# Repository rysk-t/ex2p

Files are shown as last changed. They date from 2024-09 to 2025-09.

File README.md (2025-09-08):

# Ex2p / Ex2pO
Extra lens mount for 2-photon microscope
 - extend imaging capability
 - excitation of neurons by optogenetic stimulation with narrow-band laser

|Imaging flexibility|Optogenetical stimulation (under-filled setting)|
|---|---|
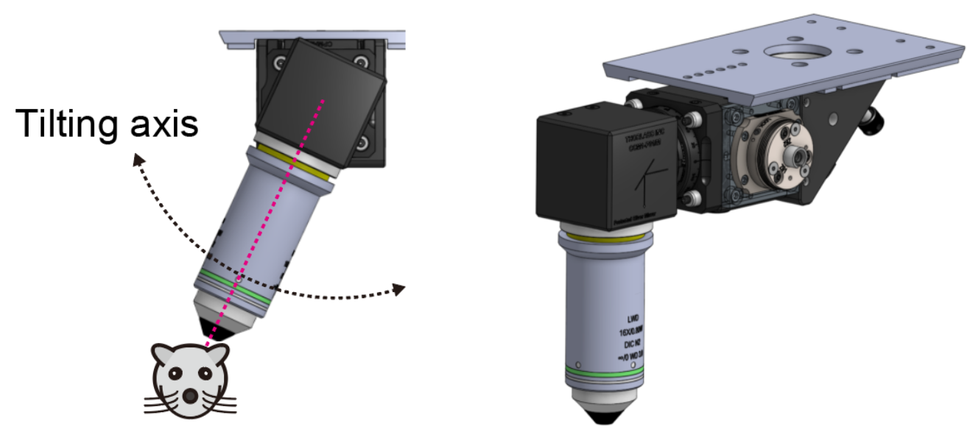
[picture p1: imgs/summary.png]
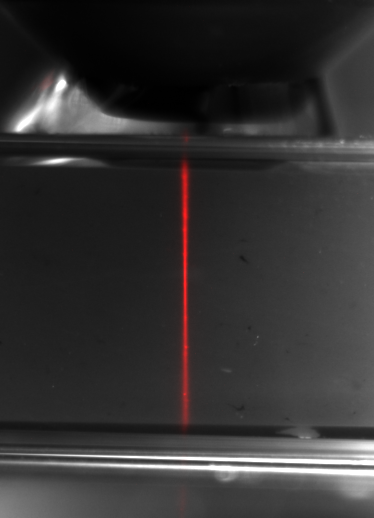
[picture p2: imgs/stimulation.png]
| | |

# Hardwares
 - Construction parts are listed in this [link](https://docs.google.com/spreadsheets/d/1m83LMHQkvfFSLj0JxW27Dom7R-7Ju0coneMxOGsIGas/edit?usp=sharing)
 - Analog discovery 2 (Digilent) is used to generate TTL signal for stimulation.

## Construction

## Ex2p
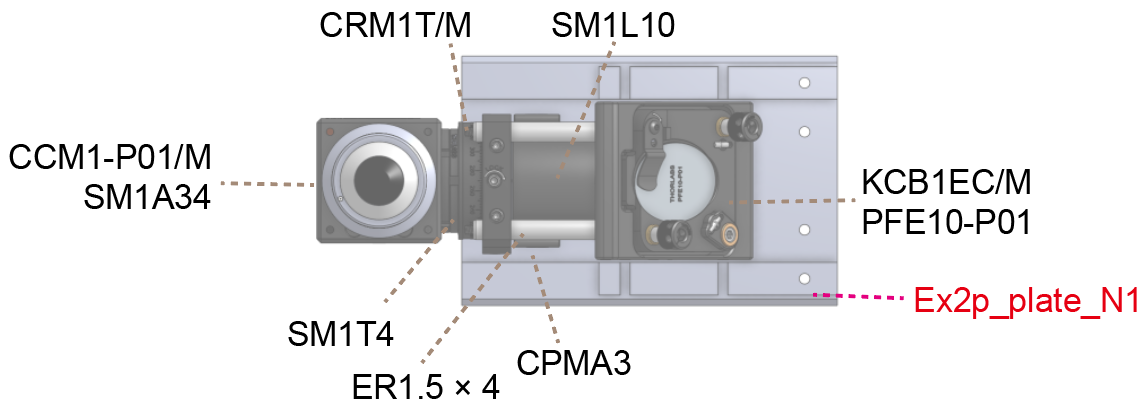
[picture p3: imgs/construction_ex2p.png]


## Ex2pO
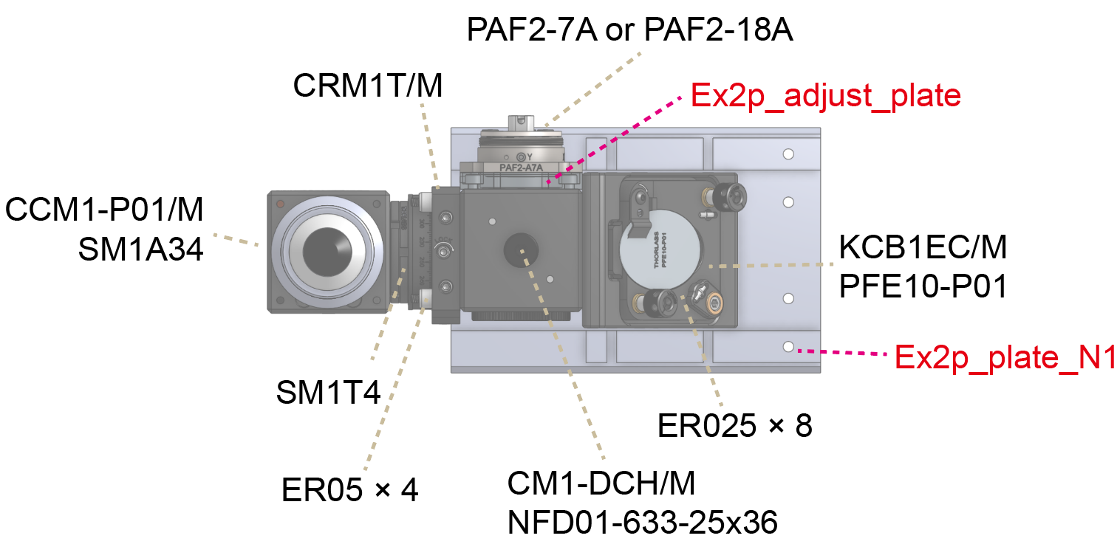
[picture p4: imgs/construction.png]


 - Red-colored parts are the original parts of the Ex2p Nikon version.
 - Most of the parts were commercial parts from Thorlab.
 - FC/APC laser input ports were attached to the dichroic mount.
   - Various narrow-band and fast switchable LD laser sources are recommended (e.g., Omicron Luxx+, Coherent OBIS LX).
  
[3d-data files (.stl)  are available](https://github.com/rysk-t/ex2p/tree/main/Ex2pO_parts).

## Circuits configuration
Using Analog Discovery 2 with a custom-made breakout board, TTL for laser modulation was quickly configurable.
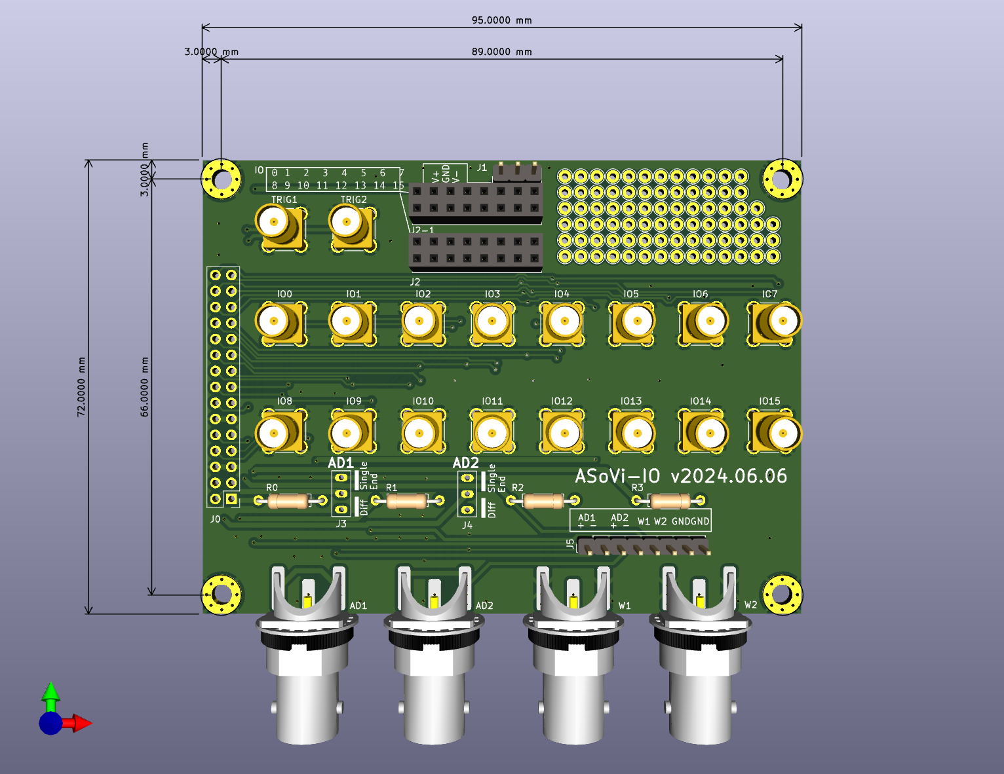
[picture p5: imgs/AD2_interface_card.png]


[PCB files (.grb)  are available](https://github.com/rysk-t/ex2p/tree/main/Ex2pO_parts/breakoutboard).

breakout board designed by Kota OKADA and Ryosuke TAKEUCHI (Nagoya University)

# Citation
Takeuchi, R. F., Ishida, R., Kamaguchi, R., Nishimura, M., Tsutsumi, K., Ito, K. N., Adachi, S., Isobe, K., & Osakada, F. (2025). An extension module for a two-photon microscope enables flexible in vivo imaging and all-optical physiology. iScience, 113525.

[https://doi.org/10.1016/j.isci.2025.113525](https://doi.org/10.1016/j.isci.2025.113525)

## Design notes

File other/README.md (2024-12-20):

# Other parts for using Ex2p
## Head-fixation of mice

 - **B1v2b.stl**: head-frame implant for mice (for two-photon imaging, Ephys, and transcranial wide-field imaging)
 - **fix_headframe.stl**: fixation metal parts L/R
 - **Head_Cover_Short2p.stl**: 3d-print parts for preventing direct stimulation of retina through eyes

|Isometric view of construction||
|---|---|
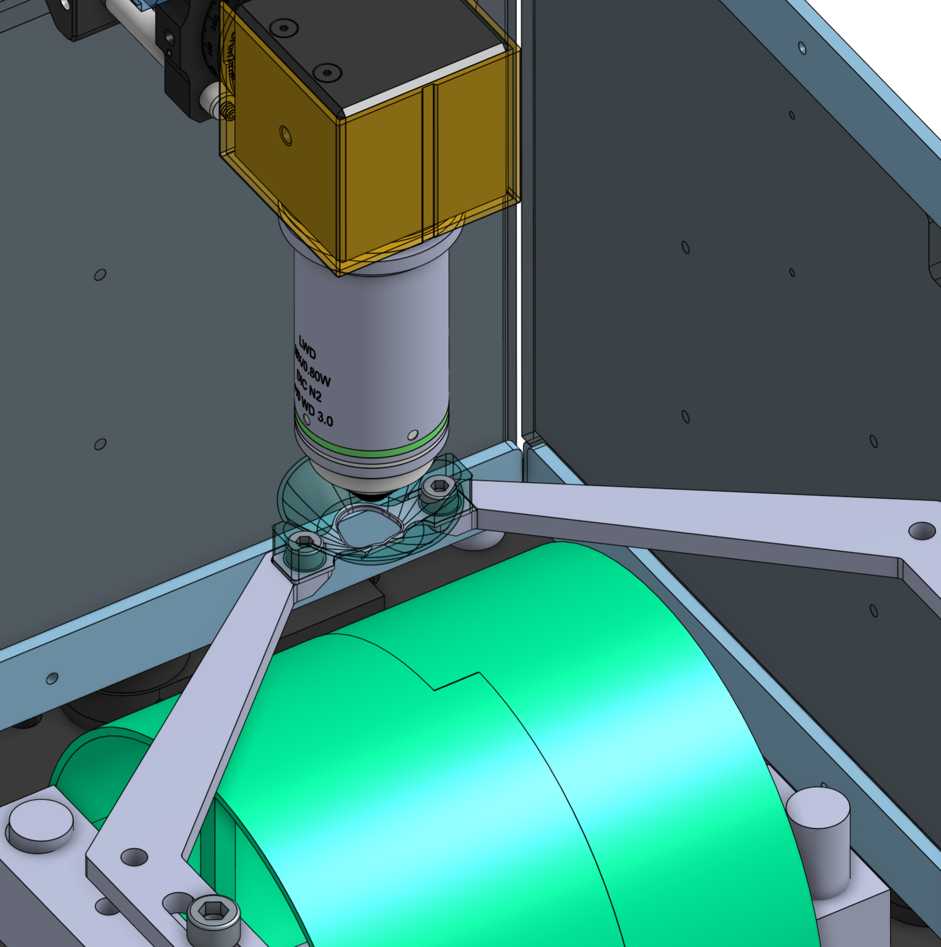
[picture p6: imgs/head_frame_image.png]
| ||

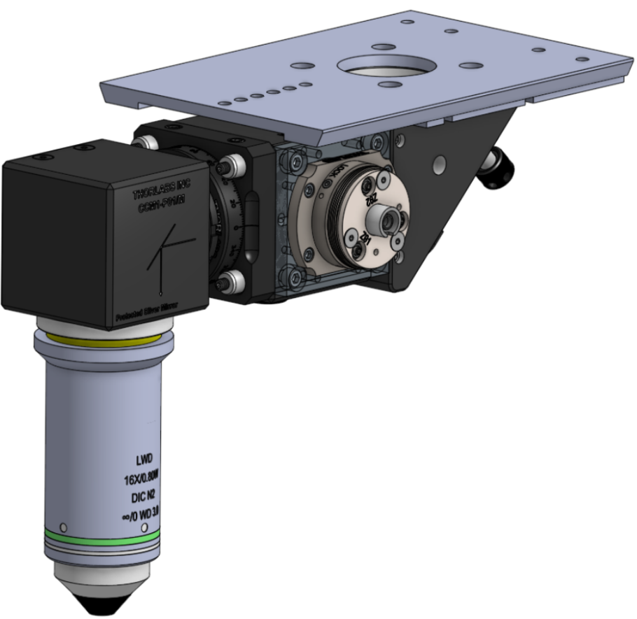
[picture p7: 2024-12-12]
imgs/isom.img.png

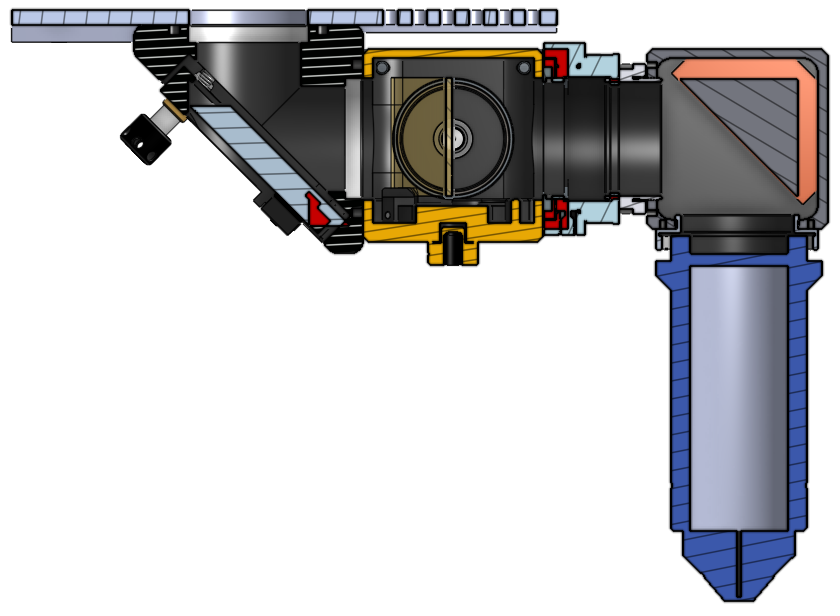
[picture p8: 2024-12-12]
imgs/orth.png

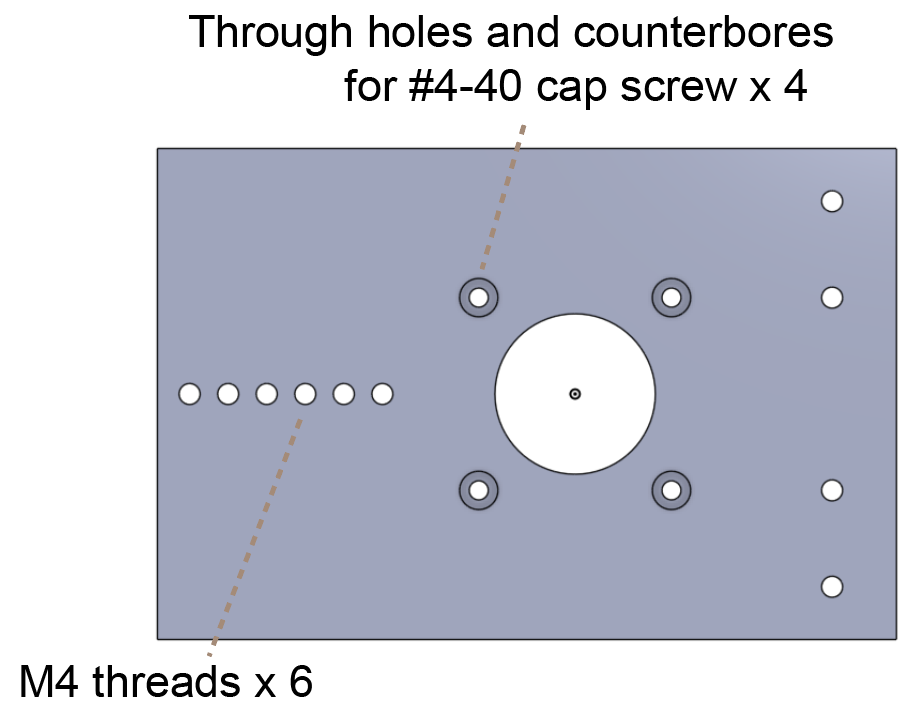
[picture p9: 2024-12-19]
imgs/hole_infos.png

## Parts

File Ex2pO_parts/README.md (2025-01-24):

# Quick guide for Ex2pO
 - Ex2pO utilizes Thorlabs 30 mm cage system for main construction.
 - FC/APC laser input ports were attached to the dichroic mount.
   - Various narrow-band and fast switchable LD laser sources are recommended (e.g. Omicron Luxx+, Coherent OBIS LX).
   - for precise alignment, Thorlabs SM05 kinematic mount is recommended.
   - any notch-dichroic filter (25x36 size) can be used. Please select the optimal wavelength for your application.

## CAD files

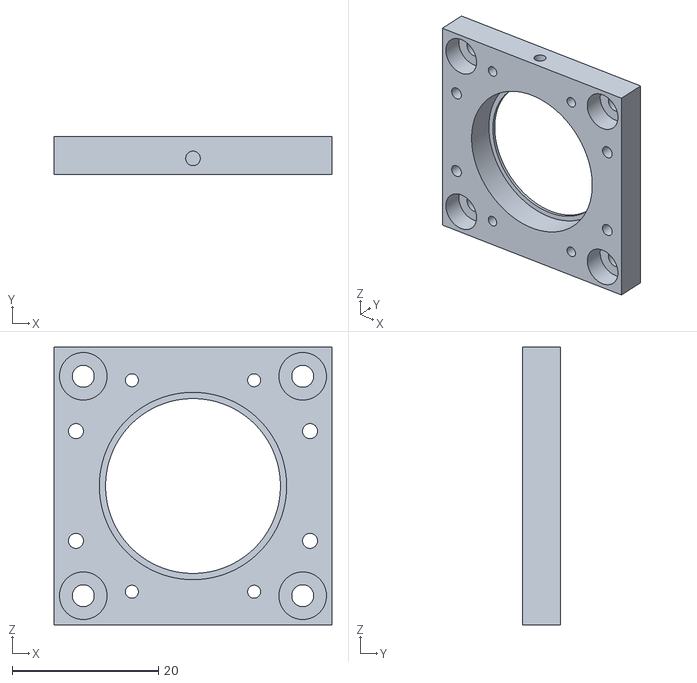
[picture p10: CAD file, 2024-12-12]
Ex2pO_parts/adjust_plate_01_v2.stl
38.0 x 5.20 x 38.0

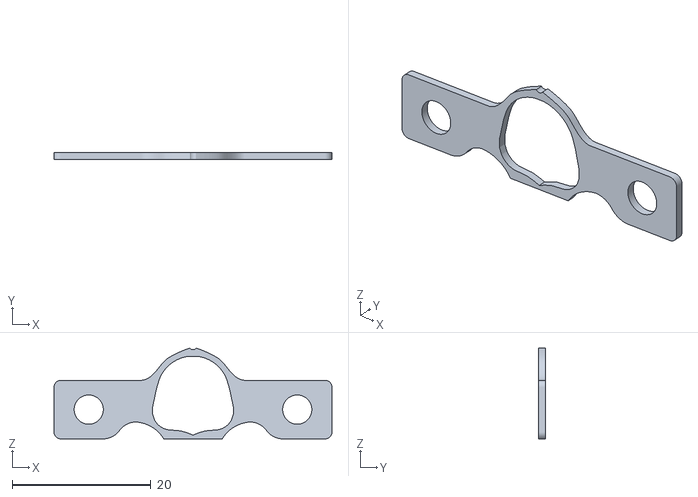
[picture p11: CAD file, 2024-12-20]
other/B1v2b.stl
40.0 x 1.00 x 13.1

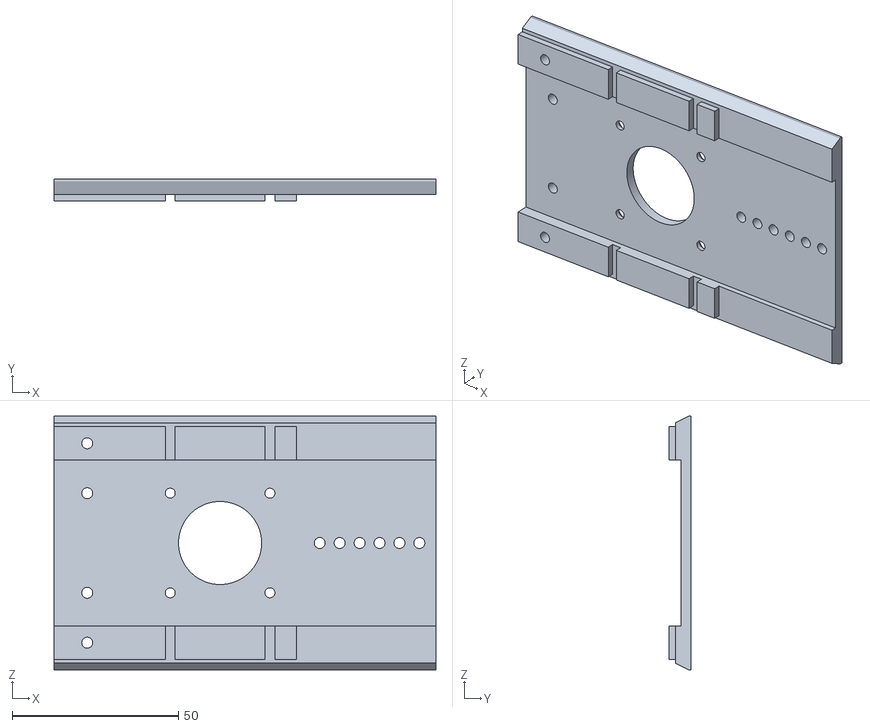
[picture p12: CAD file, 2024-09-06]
Ex2pO_parts/Ex2p_plate_N1.stl
115.0 x 6.70 x 76.4

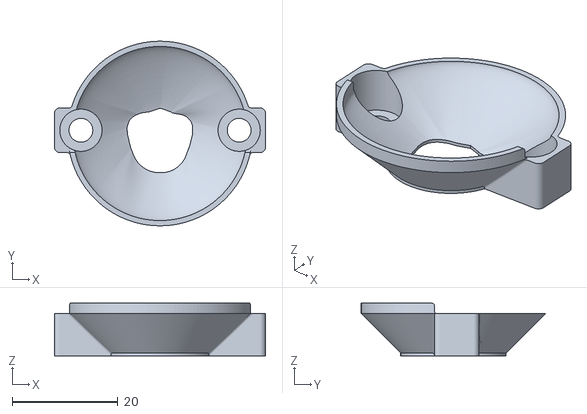
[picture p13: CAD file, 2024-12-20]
other/Head_Cover_Short2p.stl
40.0 x 35.0 x 10.0

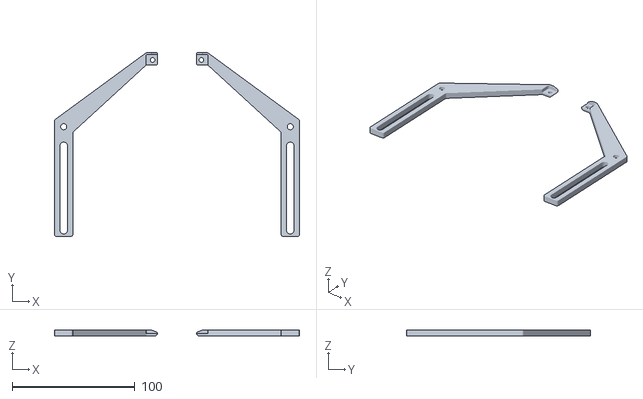
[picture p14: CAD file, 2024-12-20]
other/fix_headframe.stl
200.0 x 150.0 x 5.00

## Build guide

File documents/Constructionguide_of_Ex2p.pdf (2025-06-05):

# Assembly guide of Ex2p

## Step 1

1. Secure the four ER025 rods on plate_N1 with #4-40 low head screw.
2. Secure the CPMA3 into plate_N1 with an M4 6 mm screw.

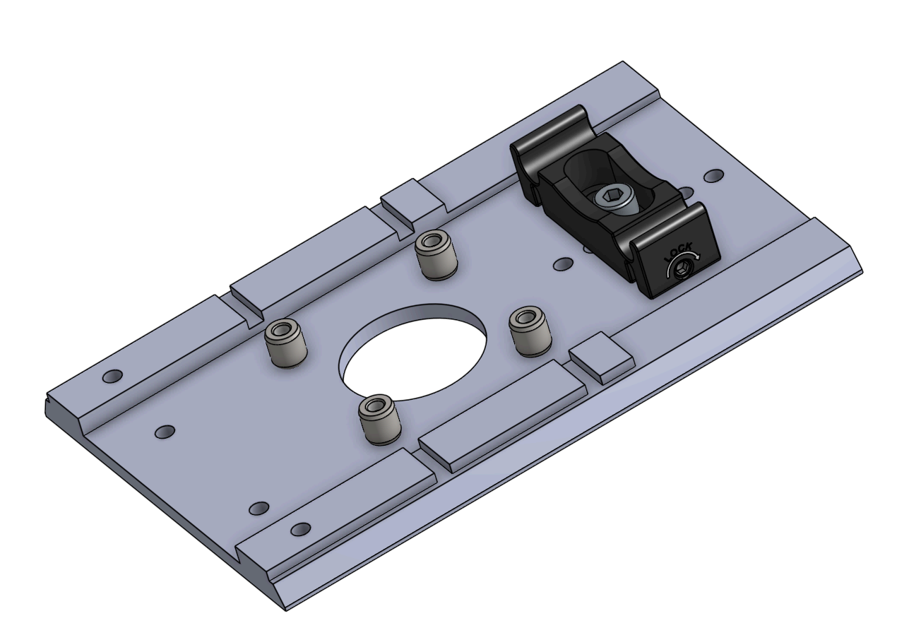
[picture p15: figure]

3. Install the Elliptical Mirror (PFE10-P01) into the KCB1EC/M.
4. Connect the four ER1.5 rods into the KCB1EC/M (Remove the set screws before connect).
5. Connect the plate_N1 and KCB1EC/M. Secure the KCB1EC/M with side screw.
6. Secure the ER1.5 with the set screw of CPMA3.

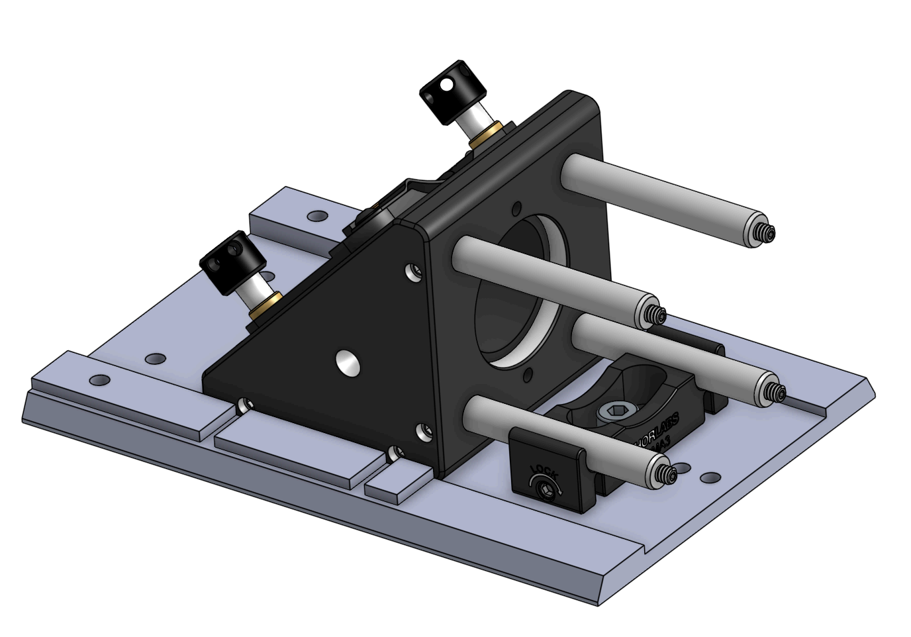
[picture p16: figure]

7. Connect the SM1L10 and KCB1EC/M.
8. Connect the CRM1T/M and CCM1-P01/M with SM1T4.

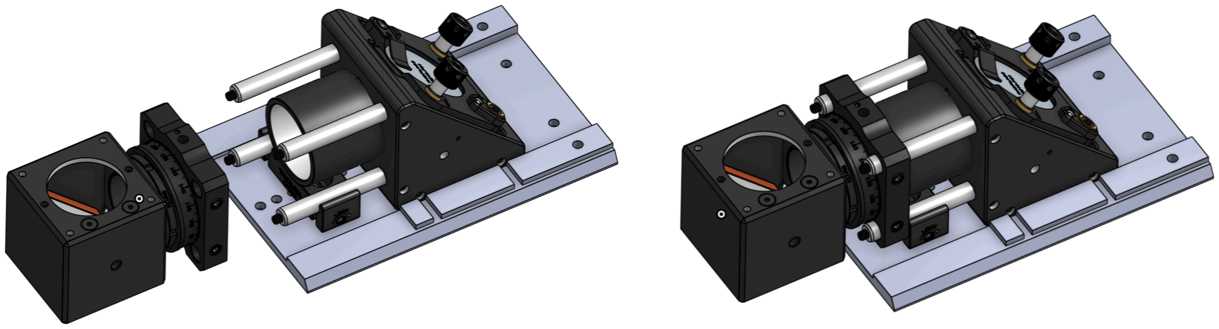
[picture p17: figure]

## Step 2

9. Secure the main unit to the microscope.
10. Secure the laser beam profiler or IR viewer target to the CM1-DCH/M (a beam profiler is recommended).
11. Center the scan mirrors of the two-photon microscope.
12. Open the shutter and emit the IR laser. Adjust the mirror on the KCB1EC/M so that the laser is centered on the laser beam profiler. Continue adjusting until the laser remains centered even when the distance along the optical axis to the laser beam profiler changes.
13. Close the shutter to stop the IR laser.
14. Adjust the angle of the objective lens.

## Notes:

- Be careful not to touch the adjustment screws on the KCB1EC/M after alignment.
- Briefly check the alignment before an experiment.
- When tilting the objective lens, loosen the lock screw(s) on the CRM1T/M, adjust the angle as needed, and then secure it.

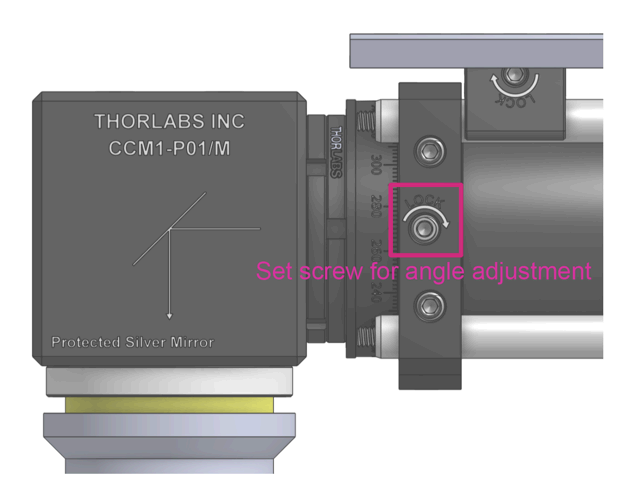
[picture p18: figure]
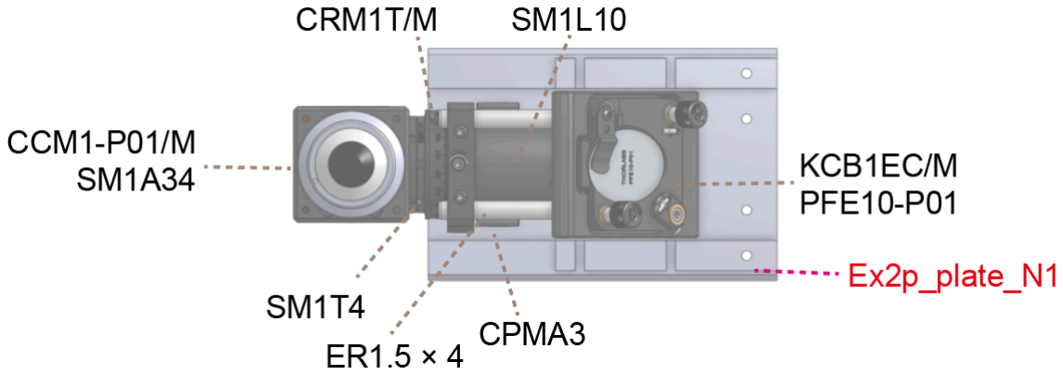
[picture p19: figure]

## Parts list

Company | Product ID | # | Detail
Thorlabs | SM1A34 | 1 | SM1A34 - Adapter with External SM1 Threads and Internal M32 x 0.75 Threads
| KCB1EC/M | 1 | KCB1EC/M - Right-Angle Kinematic Elliptical Mirror Mount with Smooth Cage Rod Bores, 30 mm Cage System and SM1 Compatible, M4 and M6 Mounting Holes
| PFE10-P01 | 1 PFE10-P01 - 1" Protected Silver Elliptical Mirror, 450 nm - 20 µm
| CCM1-P01/M | 1 | CCM1-P01/M - 30 mm Cage Cube-Mounted Protected Silver Turning Mirror, M4 Tap
| SM1L10 | 1 | SM1L10 - SM1 Lens Tube, 1.00" Thread Depth, One Retaining Ring Included
| ER025 | 4 | ER025 - Cage Assembly Rod, 1/4" Long, Ø6 mm
| ER1.5-P4 | 1 ER1.5-P4 - Cage Assembly Rod, 1.5" Long, Ø6 mm, 4 Pack
| CRM1T/M | 1 | CRM1T/M - Cage Rotation Mount for Ø1" Optics, SM1 Threaded, M4 Tap
| SM1T4 | 1 | SM1T4 - SM1 (1.035"-40) Coupler, External Threads, Fixed Shoulder and Locking Ring
| CPMA3 | 1 CPMA3 - Snap-On 30 mm Cage Mounting Bracket, #8 (M4) Slot
DIY parts | Ex2p_plate_N1 | 1
Other | #4-40 low head cap screws | 4
| SPW502 | 1 | SPW502 - Spanner Wrench for Slotted SM05, SM1, and C-Mount Locking Rings
Thorlabs | SM1A34 | 1 | SM1A34 - Adapter with External SM1 Threads and Internal M32 x 0.75 Threads
| KCB1EC/M | 1 | KCB1EC/M - Right-Angle Kinematic Elliptical Mirror Mount with Smooth Cage Rod Bores, 30 mm Cage System and SM1 Compatible, M4 and M6 Mounting Holes
| PFE10-P01 | 1 PFE10-P01 - 1" Protected Silver Elliptical Mirror, 450 nm - 20 µm
| CCM1-P01/M | 1 | CCM1-P01/M - 30 mm Cage Cube-Mounted Protected Silver Turning Mirror, M4 Tap
| SM1L10 | 1 | SM1L10 - SM1 Lens Tube, 1.00" Thread Depth, One Retaining Ring Included

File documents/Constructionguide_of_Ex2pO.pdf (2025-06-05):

## Assembly guide of Ex2pO

## Step 1

1. Install the Elliptical Mirror (PFE10-P01) into the KCB1EC/M.
2. Install the Dichroic Mirror (NFD01-633) into the CCM1-P01/M.
3. Screw the SM1CP2 onto the side of the CCM1-P01/M.
4. Screw the adjust_plate_v2 onto the face of the CCM1-P01/M, opposite the SM1CP2.
5. Screw the Fiber Port (e.g. PAF2-7A or PAF2A-18A) into the adjust_plate_v2.
6. Screw the four ER025 rods into the CCM1-P01/M. Remove the remaining set screws.
7. Connect the CCM1-P01/M and the KCB1EC/M. Tighten the side screws on the KCB1EC/M.

## Step 2

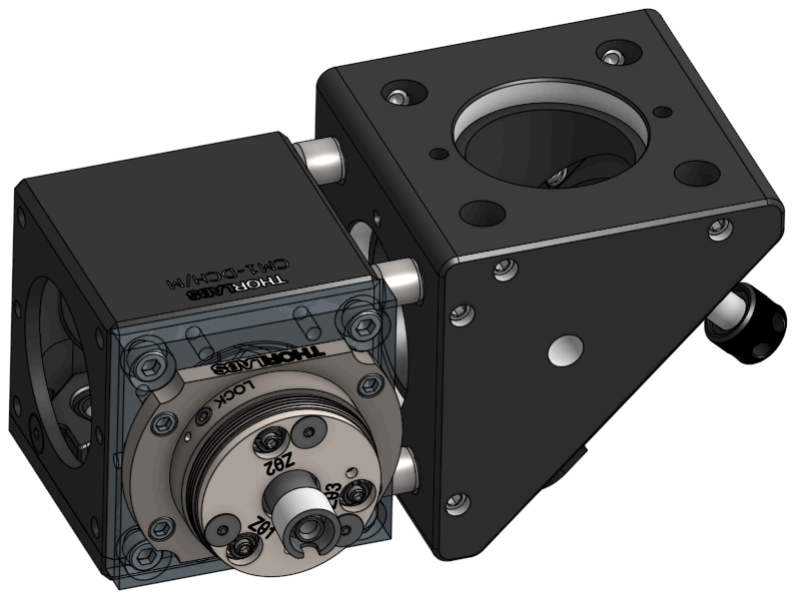
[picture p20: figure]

8. Screw the ER05 rods into the face opposite the ER025 rods.
9. Pass the CRM1T/M over the ER05 rods and secure it.
10. Secure the CRM1T/M and CM1-DCH/M together using the SM1T4 (tighten firmly with the SPW502 spanner wrench).

## Step 3

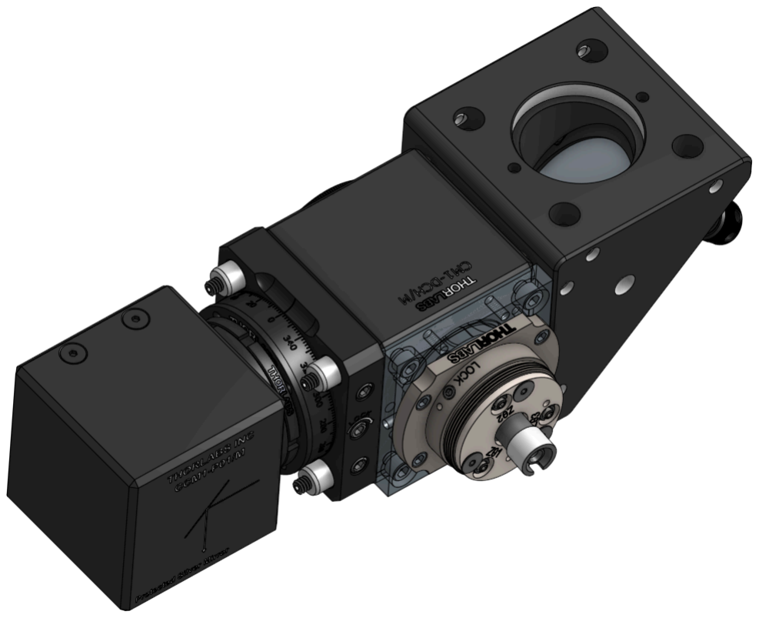
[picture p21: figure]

11. Remove all setscrews from the four ER025 rods.
12. Install this assembly on top of the KCB1EC/M. Tighten the side screws to secure it.
13. Secure plate_N1 from the top using #4-40 Low-head screws.
14. Install the blocking filter (e.g., FESH600 for 638 nm laser) in front of the detector.

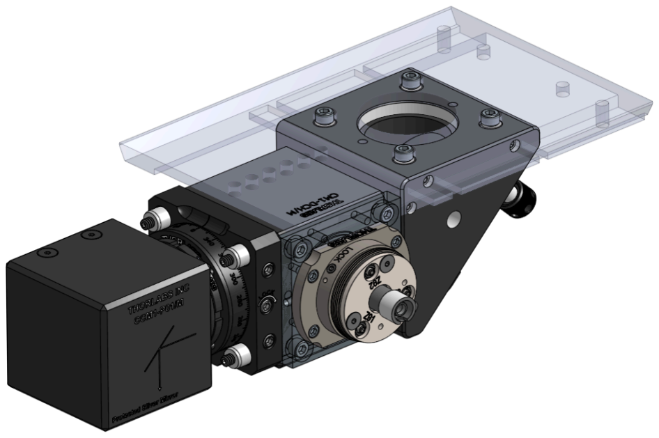
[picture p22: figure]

## Step 4

15. Secure the main unit to the microscope.
16. Secure the laser beam profiler or IR viewer target to the CM1-DCH/M (a laser beam profiler is recommended).
17. Center the scan mirrors of the two-photon microscope.
18. Open the shutter and emit the IR laser. Adjust the mirror on the KCB1EC/M so that the laser is centered on the laser beam profiler. Continue adjusting until the laser remains centered even when the distance along the optical axis to the laser beam profiler changes.
19. Close the shutter to stop the IR laser.
20. Insert the fiber for the 1P (one-photon) laser into the PAF2-7A/PAF2A-18A. Adjust the screws on the PAF2-7A/PAF2A-18A so that the 1P laser is centered on the laser beam profiler. Additionally, adjust the collimation if necessary.

## Notes:

- Be careful not to touch the adjustment screws on the KCB1EC/M.
- Briefly check the alignment before an experiment.
- When tilting the objective lens, loosen the lock screw(s) on the CRM1T/M, adjust the angle as needed, and then secure it.

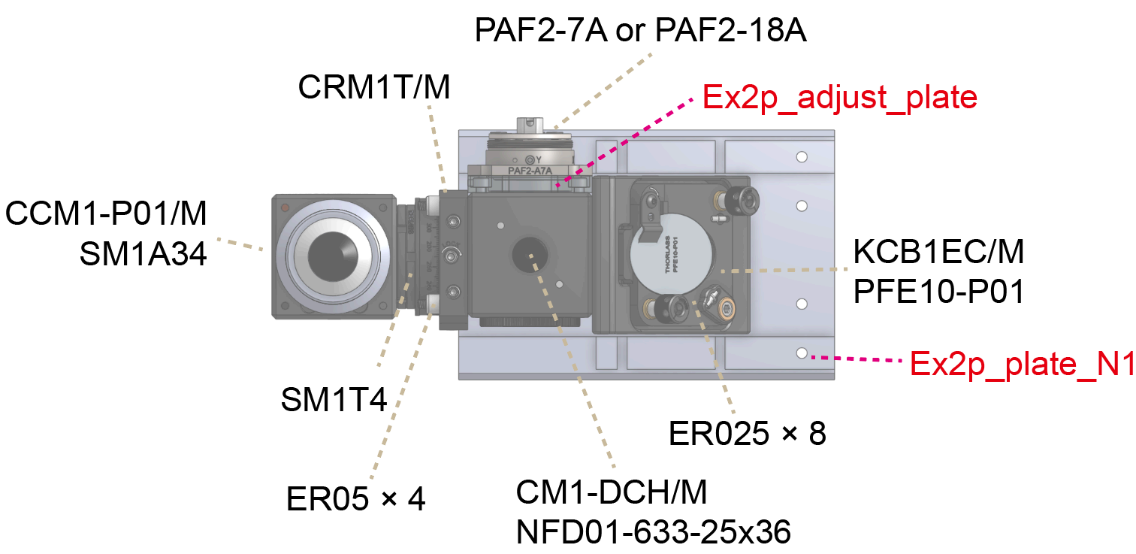
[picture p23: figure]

## Parts list

Company | Product ID | # | Detail
Thorlabs | SM1A34 | 1 | SM1A34 - Adapter with External SM1 Threads and Internal M32 x 0.75 Threads
| CCM1-P01/M | 1 | CCM1-P01/M - 30 mm Cage Cube-Mounted Protected Silver Turning Mirror, M4 Tap
| SM1T4 | 1 | SM1T4 - SM1 (1.035"-40) Coupler, External Threads, Fixed Shoulder and Locking Ring
| CRM1T/M | 1 | CRM1T/M - Cage Rotation Mount for Ø1" Optics, SM1 Threaded, M4 Tap
| ER05-P4 | 1 | ER05-P4 - Cage Assembly Rod, 1/2" Long, Ø6 mm, 4 Pack
| CM1-DCH/M | 1 | CM1-DCH/M - 30 mm Cage Cube with Dichroic Filter Mount (Metric)
| SM1CP2 | 1 | SM1CP2 - Externally SM1-Threaded End Cap
| ER025 | 8 | ER025 - Cage Assembly Rod, 1/4" Long, Ø6 mm
| KCB1EC/M | 1 | KCB1EC/M - Right-Angle Kinematic Elliptical Mirror Mount with Smooth Cage Rod Bores, 30 mm Cage System and SM1 Compatible, M4 and M6 Mounting Holes
| PFE10-P01 | 1 | PFE10-P01 - 1" Protected Silver Elliptical Mirror, 450 nm - 20 µm
| FESH0600 | 1 | FESH0600 - Ø25.0 mm Shortpass Filter, Cut-Off Wavelength: 600 nm
| PAF2A-18A | 1 | PAF2A-18A - FiberPort, FC/APC, f=18.4 mm, 350 - 700 nm, Ø3.01 mm Waist
Semrock | NFD01-633-25x36 | 1 | 633 nm StopLine® notch laser dichroic beamsplitter
DIY parts | plate_N1 | 1 | https://github.com/rysk-t/ex2p/tree/main/Ex2pO_parts
| adjust_plate_v2 | 1 | https://github.com/rysk-t/ex2p/tree/main/Ex2pO_parts
Other | #2-56 cap screws | 4
| #4-40 low head cap screws | 8
| SPW502 | 1 | SPW502 - Spanner Wrench for Slotted SM05, SM1, and C-Mount Locking Rings

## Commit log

2024-09-06 add plate data for nikon microscopy
    [Ex2p_plate_N1.stl]
2024-12-12 add images and stl
    [adjust_plate_01_v2.stl]
2024-12-12 add .gbr files
    add .gbr files
    [AD2_interface_card-B_Cu.gbr, AD2_interface_card-B_Mask.gbr, AD2_interface_card-B_Silkscreen.gbr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]
2024-12-20 add images
    [B1v2b.stl, Head_Cover_Short2p.stl, fix_headframe.stl]
